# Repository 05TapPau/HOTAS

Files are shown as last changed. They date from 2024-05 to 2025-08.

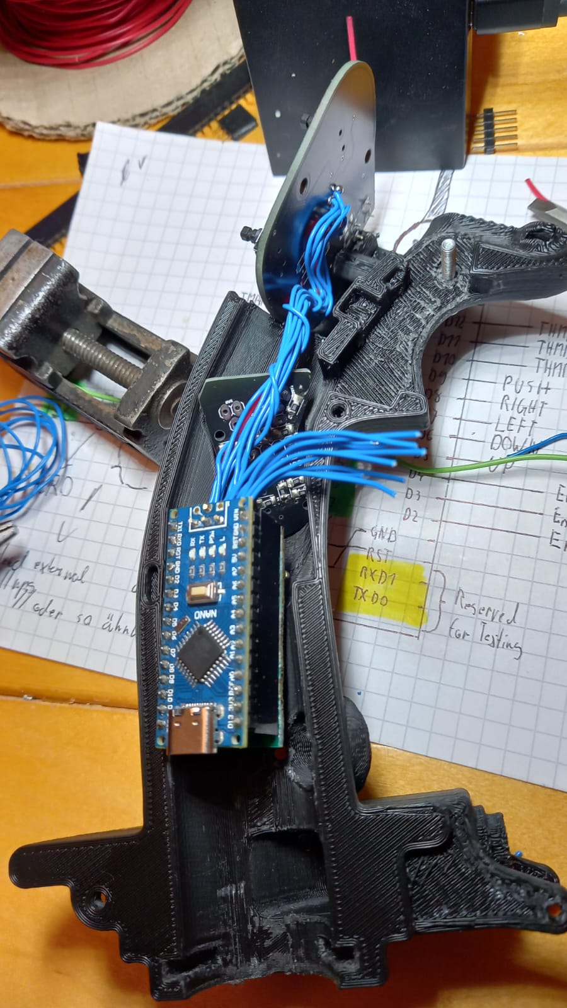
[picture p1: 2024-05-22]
Images/Assembly_03.jpg

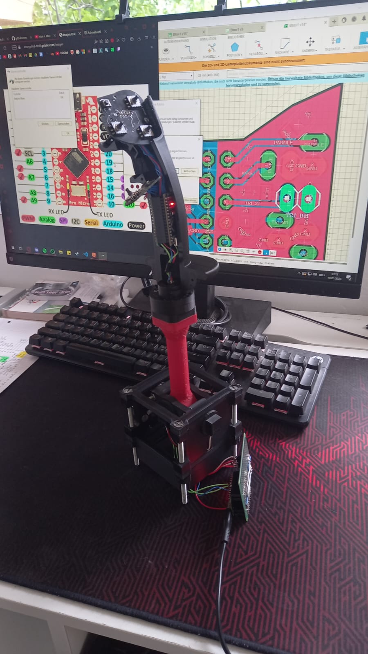
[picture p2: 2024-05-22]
Images/Testing_01.jpg

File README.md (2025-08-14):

Hi, im a student in a technological highschool and this is a project I did.
in this repo you should be able to find all things and sources to somewhat clone my project
well its not gonna be a copy and paste project for anyone trying cuz you have to figure our some stuff on your own or you ask me rreddit: https://www.reddit.com/user/gimme_da_meme/

maybe i will add some links in here sometime but right ow its 23:28 where im at and i wanna go to sleep so yeah sorry for that i guess

anyways have a great night/morning/day

Copyright (C) 2025 "Paul Tappeiner" aka "05TapPau"
These Sources are freely available: 
You may distribute and/or modify them under the terms of the GNU General Public License, either 
according to version 3 of the license or any later version, as published by the Free Software Foundation.
These Sources are distributed in the hope that they will be useful, but WITHOUT ANY WARRANTY; even without 
the implied warranty of MERCHANTABILITY or FITNESS FOR A PARTICULAR PURPOSE. 
For further details, see the GNU General Public License.

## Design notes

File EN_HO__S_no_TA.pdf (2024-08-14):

Name | | class school
5.10.2023 | - | 23.05.2024

Yearly project: HO(TA)S

Hands on (Throttle and) Stick

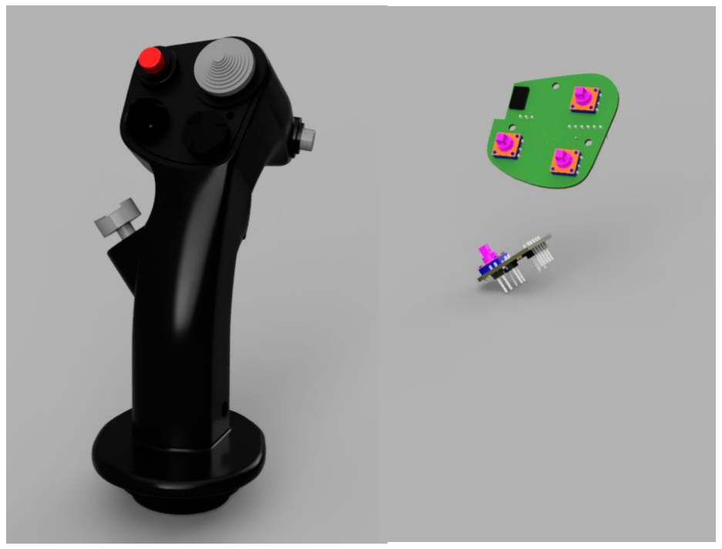
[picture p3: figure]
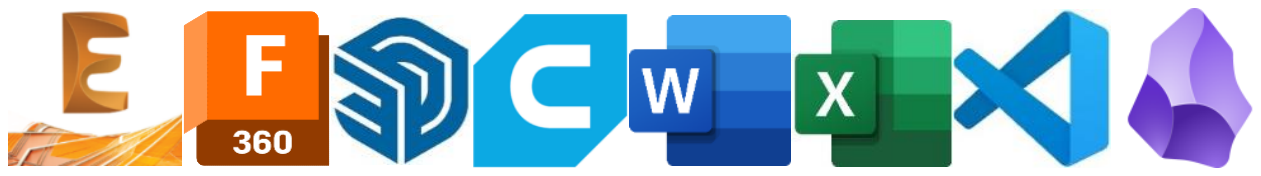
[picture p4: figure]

Contents

Projevtoverview

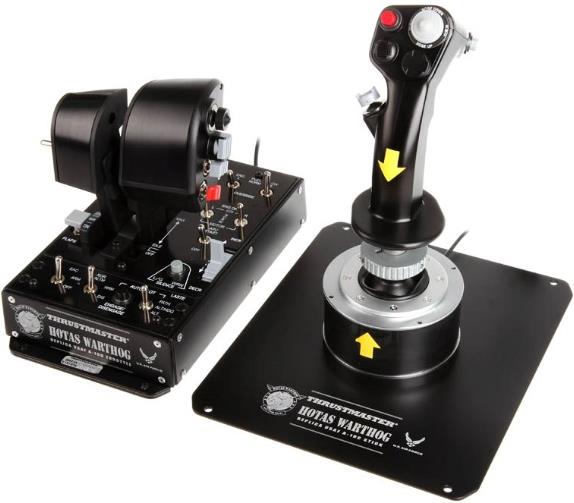
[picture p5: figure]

A Hands On Throttle And Stick (Image to the right) is a computer input device that visually resembles the control surfaces that can be found in an airplane/helicopter. It is mainly used to learn and train the flying of real aircraft in simulators, and for some years now they have also been used in the entertainment sector to control flying objects (airplanes, helicopters, spaceships, etc.) in computer games and simulations such as DCS, WarThunder, etc. The main module of the HOTAS, the flightstick or joystick, performs the main functions of “roll” and “pitch” (illustration on the right). The fact that these axes are corrected analogously in a HOTAS means that much greater precision can be achieved than would ever be possible with a keyboard. There are also buttons on the stick for entering other commands.

Main Goal

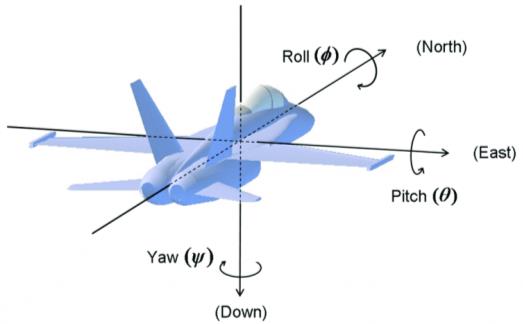
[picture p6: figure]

The aim of the project was to work on and complete a project that was started outside of school. It should consist of two Arduinos, one of which is in the base and another in the joystick. These two µCs are to exchange the required data via I2C and pass it on to the PC via the USB interface. In addition to the obvious advantages of having more pins available, the choice of two Arduinos also offers the advantage of being able to add further modules via the I2C bus using the Arduino in the base, with just a few lines of code.

Optional Goals

Optional 1

For the time being, the addition of a further module was planned as an optional target. This module would be the throttle. It is usually located to the left of the pilot in real aircraft and allows stepless control of the thrust in airplanes or the pitch of the rotors in helicopters as well as control over the speed of the turbine.

Optional 2

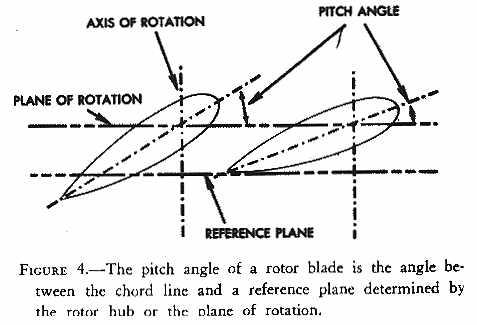
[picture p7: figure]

Another option was the output of data, which could be retrieved from the simulation via third-party software, on digital or analog displays mounted near the joystick. However, this goal was only a rough idea from the beginning and was never really started. However, it would be a good placeholder if there was still a lot of time left at the end of the year. However, this was not the case and so this optional goal was already discarded at the end of January.

Implementation

Project planning

Research 3D model

The project was started with research on different joystick models to get a feeling for what is needed on a joystick. After some first own
drawing attempts (pictures on the right), it was
decided to use an open source 3D model of a F-16 /
A10 joystick. As it turned out that it would take a lot of time to draw it completely by oneself. It was decided to use the 3D model from JFlyer81, as it is based on a 3D scan of a real joystick.

However, since the final joystick consists not only of
a joystick, but also a part for mounting the joystick,
the so-called gimbal. The basic idea here was a

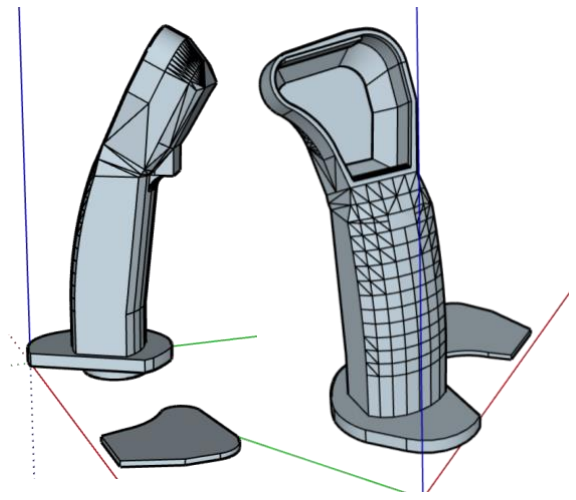
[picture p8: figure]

construct that could rotate around two axes. During the first attempts to design our own gimbal, we quickly realized that it was very difficult to draw a concept that would keep the force that counteracts the movement of the joystick linear and prevent it from noticeably “snapping” in the middle position, which would be optimal for a joystick. After lengthy research, a design for a gimbal that roughly met the requirements was found (olukelo >> Thingiverse). This gimbal was then used as the basis and further modified.

3D drawing/adjustment

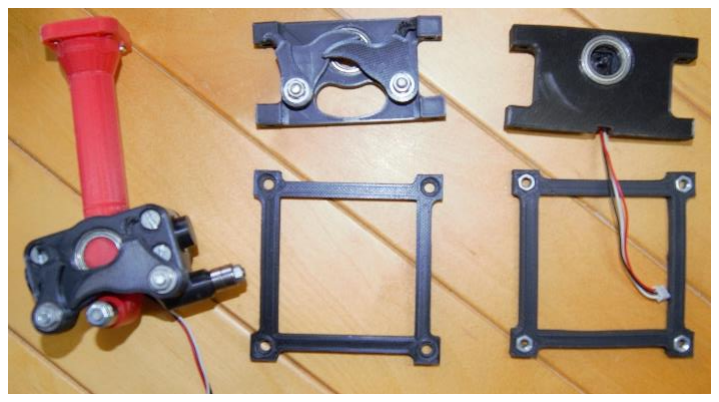
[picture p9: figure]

These modifications were mainly related to the adjustment of the exploitation method from Hall sensors to poorer/less precise potentiometers and various smaller adjustments concerning ball bearings, cable ducts and mounting points for nuts etc.. The next big and important adjustment was the modification of the joystick shaft which firmly connects the gimbal and joystick.
The original connection was a pure
plug-in connection which relied purely
on the friction of the materials. There was also a connection option based on two M5 screws, but I also found this unsuitable as I wanted the joystick to be able to be replaced quickly if necessary.

As a result, I redesigned the connection
mechanism into a variant that locks. The joystick is pressed onto the connector with a 45° turn to the base and turned back to a 0° position, whereby the joystick locks with the shaft and is firmly connected to it. After an unsuccessful attempt with a makeshift circuit board, the electronic connection is provided by a push-in connector, which is normally used for audio systems in the avionics sector (see picture on the left). After the basic model of the complete joystick assembly was ready, the planning of the electrical components was started.

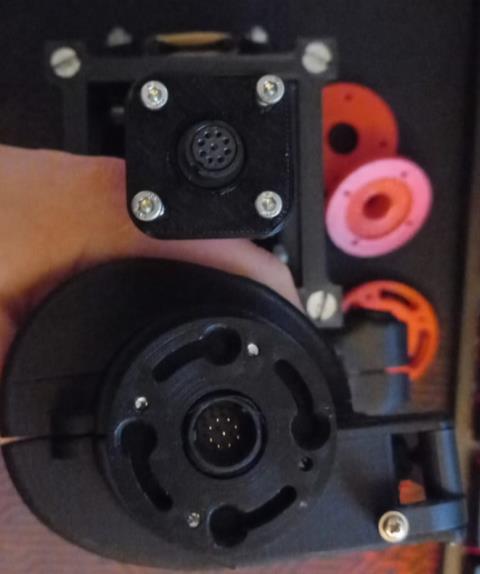
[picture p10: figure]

2 “Twist on quickconect”, gimbal top, joystick bottom

1 Individual components of the gimbal are recognizable ball bearings and potentiometers

Electronic components

The basic idea here was to have an independent Arduino in the joystick which takes care of reading out the various buttons and sending them to another Arduino which then takes care of sending this data to the PC. Reading the 26 buttons in the joystick should still prove to be a hurdle, but more on that later. In the base of the joystick is an Arduino Micro, which has the properties to appear as a keyboard/mouse/controller under Windows. This reads the data sent from the Arduino Nano and passes it on, and also passes on the values of the potentiometers.

The potentiometers used here were potentiometers which had a rotation range of approx. 90°, instead of the classic 300°-320°, which corresponded almost exactly to the possible rotation angle of the gimbal.

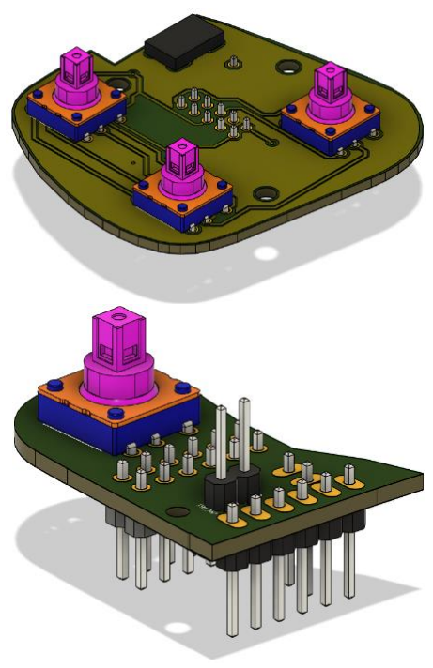
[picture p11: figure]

In the first prototype, the buttons were small holders for
five 5*5*3 mm buttons attached to the housing with screws. However, this structure was very complex, unreliable and prone to errors. It was therefore decided to replace these brackets with an integrated 5-way button, which, however, requires a circuit board. The next step was therefore to design one or two circuit boards that corresponded to the joystick housing, a cut was made in the housing so that the circuit boards could be firmly installed in the housing. This process was repeated for the side circuit board and continued accordingly. As there is a front board and a thumb board, which are in different positions (on the left where the thumb is and on top of the front panel).

Electronic implementation

As the Arduino Nano only has 14 digital and 8 analog pins, two of which are lost for the communication between the two Arduinos via I2C, only 20 pins remain. As already mentioned, there are 26 buttons in the joystick. However, since the 5 way buttons have a common supply pin, they can be switched on and off sequentially and the 5 different lines of the respective pins can be combined with the corresponding ones. This means that the 15 pins that would have to be used for this can be reduced to 5 pins for reading out the statuses and 3 pins for switching the button units on and off. For the other

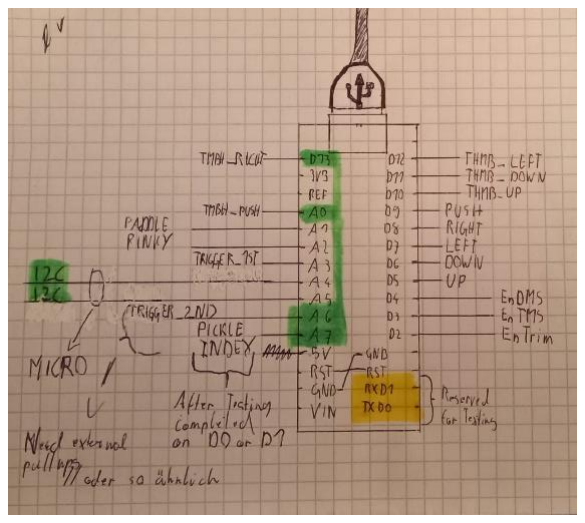
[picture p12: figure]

3 Pinout/use of pins => Nano mounted in the stick itself buttons, these were not solved using the same system, but were pulled individually onto the µC, as there were now enough pins available and the wiring would not have been much easier.

Schematic front PCB:

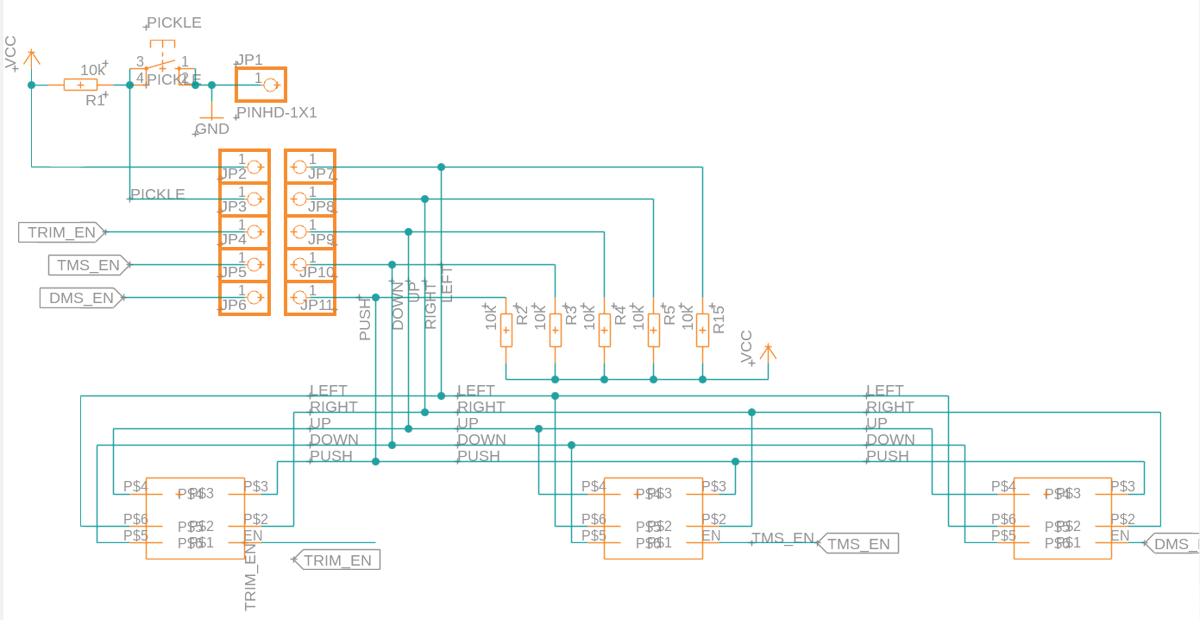
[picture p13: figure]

4 Schematic front PCB

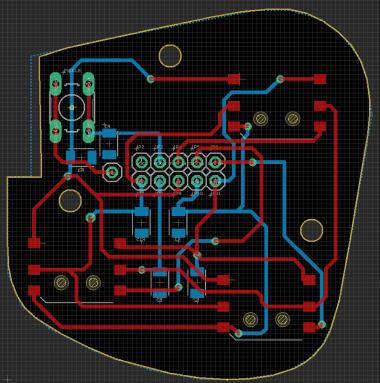
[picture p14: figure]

Here you can clearly see how the outputs of the various button units all go to the same five conductors. It should be noted that since the pins are all configured to pull-ups, only the unit that is currently switched to GND by the µC can control the outputs. It should also be mentioned here that the names TRIM, TMS, DMS refer to control characteristics of the
airplane, I refer to the
illustration on the right,
and these have only been adopted for orientation purposes.

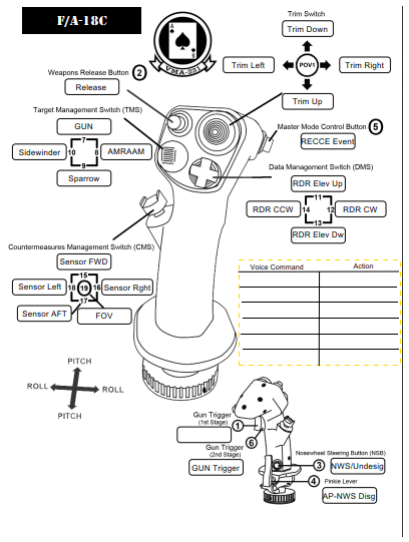
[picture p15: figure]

5 Related PCB

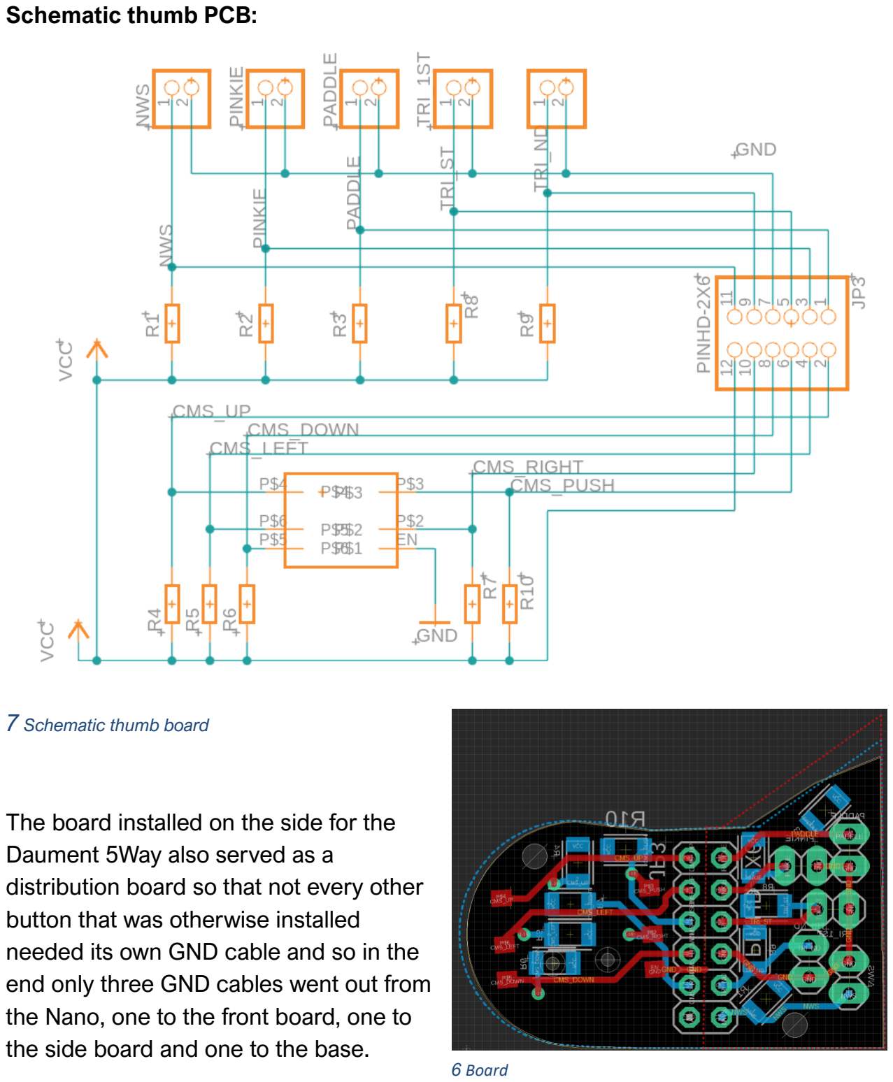
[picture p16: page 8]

Schematic thumb PCB:

7 Schematic thumb board

The board installed on the side for the Daument 5Way also served as a distribution board so that not every other button that was otherwise installed needed its own GND cable and so in the end only three GND cables went out from the Nano, one to the front board, one to the side board and one to the base.
6 Board

Wiring

In practice, the cabling no longer looked so neat and tidy, as everything had to fit into a very limited space. On the right you can see that, despite the reduction to 10 cables, it became a little confusing.

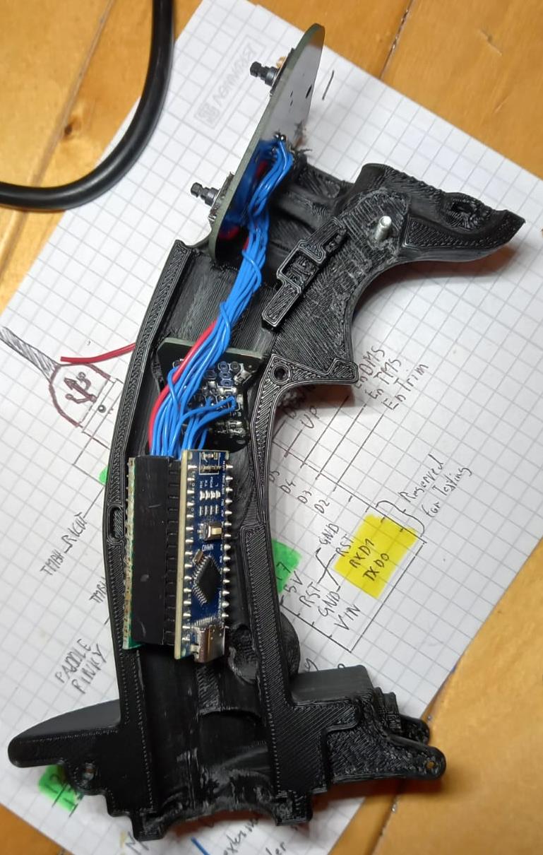
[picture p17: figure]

Software

The software running on the Arduinos was developed at the same time as the setup was being planned. If you start at the base, there is a library on the Arduino Micro which ensures that the Micro appears as an HID. This is then extended with the necessary joystick code so that the Micro can work or be recognized as a joystick.

The Micro writes the data read out via the potentiometers to the respective X/Y axes and accepts the incoming data from the buttons via I2C and passes it on to the PC.

The nano in the joystick assumes the underlying role here and sends the states of the buttons via I2C on request from the micro. This communication takes place via the Arduino's own I2C library.

8 Joystick during soldering

9 Joystick during soldering

Finalization and testing phase

The actual test phase of this project was always continuous alongside the development, as a first prototype already existed. This provided a great starting point, as you could switch from the digital to the physical while planning something and get a good idea of what still needed to be changed and adapted. During the finalization phase, something unfortunately went wrong with the delivery of the circuit boards via DHL, which meant that the boards only arrived a week late, which limited the schedule somewhat but was not worth mentioning until the end. Once all the parts were on site, the assembly could begin and after about two to three afternoons the final assembly was completed. The code that had already been written in March was then adapted a little and loaded onto the controllers. After a few
small adjustments (filing, soldering), the final
prototype was ready and the protocol was also

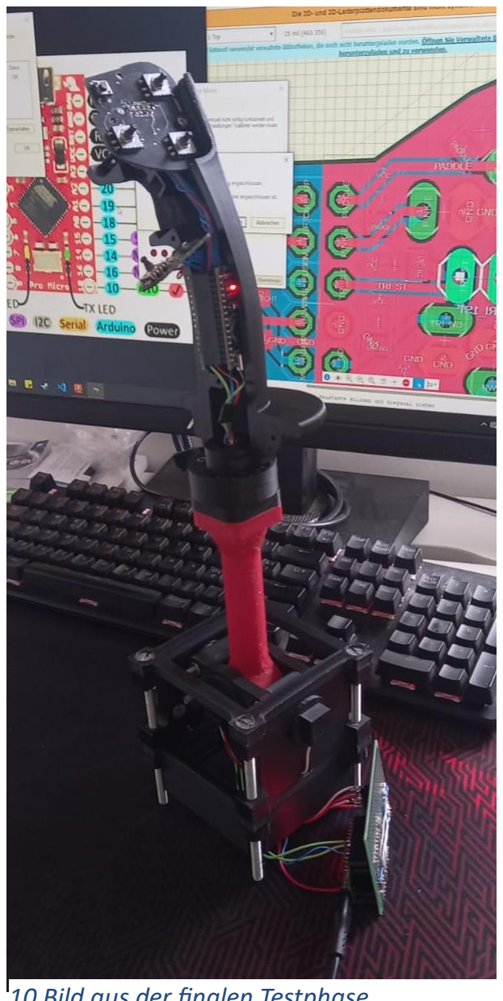
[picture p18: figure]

finalized. | 10 Bild aus der finalen Testphase

Sources:

OpenSource Code

used Joystick-Lib (https://github.com/MHeironimus/ArduinoJoystickLibrary)

GitHub for this project (https://github.com/05TapPau/HOTAS_Base_module)

3D-Models

Stick Base unedited (https://www.thingiverse.com/thing:4544115)

Gimbal unedited (https://www.thingiverse.com/thing:2496028)

GitHub edited stl s (https://github.com/05TapPau/HOTAS)

Images reference etc

https://shop.thrustmaster.com/it_it/hotas-warthog.htmlhttps://www.researchgate.net/figure/An-illustration-of-the-three-angles-yaw-pitch-and-roll-returned-by-the-Hype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 (https://www.researchgate.net/figure/An-illustration-of-the-three-angles-yaw-pitch-and-roll-returned-by-the-Hyper-IMU_fig1_329603549)

https://www.digitalcombatsimulator.com/upload/iblock/49a/HOTAS.png

- You should also be able to find images on the GitHub.

Legal or smth I aint no lawyer

If you own the intellectual right to any of the above mentioned things and im not allowed to use them please let me know I am pretty sure that this should al be okay but anyways im just human and probably also make mistakes.

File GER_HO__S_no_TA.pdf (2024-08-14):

Name | | class school
5.10.2023 | - | 23.05.2024
| FÜLA

Projekt: HO(TA)S

Hands on (Throttle and) Stick

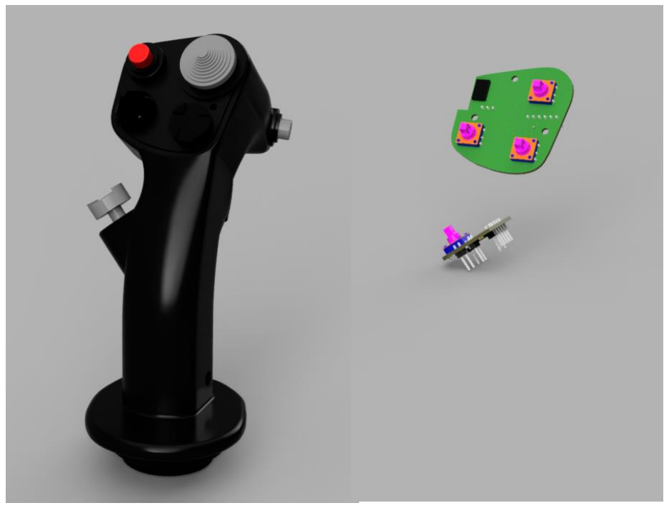
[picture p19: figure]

Inhalt

Projektübersicht


Ein Hands On Throttle And Stick (Abbildung rechts) ist ein Computereingabegerät welches optisch an die Kontrollflächen, welche in einem Flugzeug/Helikopter gefunden werden können, erinnert. Es wird hauptsächlich verwendet, um in Simulatoren das Fliegen von echten Fluggeräten zu Lernen und zu trainieren, seit einigen Jahren werden sie auch im Unterhaltungssektor zum Lenken von Flugobjekten (Flugzeuge, Hubschrauber, Raumschiffe etc.) in Computerspielen und Simulationen wie DCS, WarThunder etc. Das Hauptmodul des HOTAS, der Flightstick oder Joystick, übernimmt die Hauptsächlichen Funktionen von „Roll“ und „Pitch“ (Abbildung rechts). Dadurch dass diese Achsen in einem
HOTAS analog korrigiert werden, erreicht man
eine viel höhere Präzision als man mit einet


Tastatur Jeh erreichen würde. Desweitern finden sich auf dem Stick noch Knöpfe zur Eingabe von weiteren Befehlen.

Hauptziel

Das Ziel des Projektes war es ein außerhalb der Schulzeit angefangenes Projekt auszuarbeiten und fertigzustellen. Es soll aus zwei Arduinos bestehen, wovon einer sich in der Basis befindet und ein weitere im Joystick. Diese zwei µC sollen über I2C die benötigten Daten austauschen und über die USB-Schnittstelle an den PC weitergeben. Die Wahl für zwei Arduinos bietet neben den offensichtlichen Vorteilen wie, dass nun mehr Pins zur Verfügung stehen, auch den Vorteil, dass man über den Arduino in der Basis noch weiter Module über den I2C Bus, mit Wenigen Zeilen Code, hinzufügen kann.

Optionale Ziele

Optional 1


Als optionale Ziele wurden vorerst noch die Addition eines weiteren Modules vorgesehen. Dieses Modul wäre damit der Throttle oder zu Deutsch der Schubregler. Er befindet sich in echten Fluggeräten meist zur Linken des Piloten und erlaubt eine Stufenlose Kontrolle des Schubes in Flugzeugen oder Pitch der Rotoren in Hubschraubern sowohl als Kontrolle über Drehzahl der Turbine.

Optional 2

Ein weiteres Optional war die Ausgabe von Daten, welche über Dritt Software aus der Simulation geholt werden können, an Digitalen oder Analogen Anzeigen, welche in der Nähe des Joysticks montiert, werden könnten. Dieses Ziel war jedoch von Anfang an nur eine grobe Idee und wurde nie wirklich angefangen. Es wäre jedoch ein guter Platzhalter, wenn am Ende des Jahres noch viel Zeit übrig wäre. Dies war jedoch nicht der Fall und so wurde dieses optionale Ziel schon Ende Januar verworfen.

Umsetzung

Projekt-Planung

Recherche 3D Model

Gestartet wurde das Projekt mit Recherchen nach verschiedenen Joystickmodellen, um ein Gefühl dafür zu bekommen was alles nötig ist
auf einem Joystick zu haben. Nach einigen ersten
eigenen Zeichenversuchen (Bilder rechts), wurde
sich jedoch entschieden ein open source 3D-Modellen von einem F-16 / A10 Joystick zu verwenden. Da sich herausstellte, diesen komplett selbst zu zeichnen Unmengen An Zeit aufbrauchen würde. Es wurde sich für das 3D Modell von JFlyer81 (https://www.thingiverse.com/JFlyer81) entschieden, da diese auf einem 3D-Scan
eines echten Joysticks basiert.

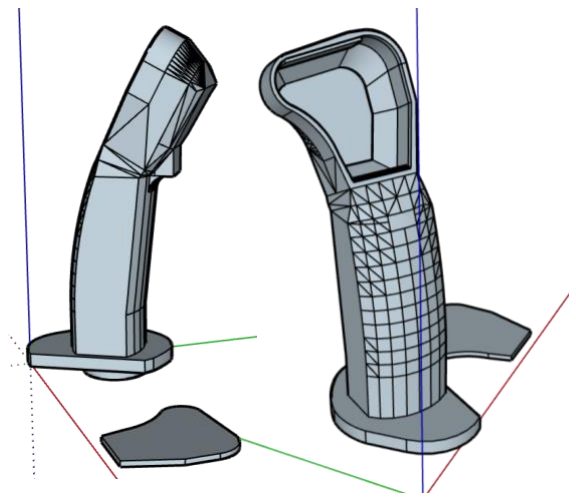
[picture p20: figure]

Da der schlussendliche Joystick jedoch nicht nur aus einem Joystick besteht, sondern auch einem Teil zur Montage des Joysticks, dem sogenannten Gimbal. Die Grundidee hier war ein Konstrukt, welches sich um zwei Achsen drehen kann. Bei den ersten Versuchen ein eigenes Gimbal zu designen wurde schnell festgestellt, dass es hier sehr schwer ist ein Konzept zu zeichnen welches die Kraft, welche der Bewegung des Joysticks entgegenwirkt, linear zu halten und ein spürbares „Einrasten“ in der Mittelposition zu verhindern, was optimal wäre für einen Joystick.

Nach längerer Recherche und Austausch mit einem Designer (olukelo (https://www.thingiverse.com/olukelo) >> Thingiverse) welcher schon ein Gimbal designt hat, welches ca. den Ansprüchen entsprach. Dieses Gimbal wurde dann als Basis verwendet und weiter modifiziert.

3D Zeichnung/Anpassung


Diese Modifikationen bezogen sich hauptsächlich auf die Anpassung der Ausbeutungsmethode von Hall Sensoren zu schlechteren/Unpräziseren Potentiometern und unterschiedlichen kleineren Anpassungen was Kugellager, Kabelschächte und befestigungspunkte für Muttern etc. angingen. Die nächste große und wichtige Anpassung war die Änderung vom Joystick-Schaft welcher
Gimbal und Joystick fest verbindet. Die
originale Verbindung war eine reine
Steckverbindung welche sich reine auf Reibung der Materialien verlies, des Weiteren gab es noch eine Verbindungsoption, welche auf zwei M5 Schrauben basiert, jedoch fand ich auch diese unpassend da der Joystick in meiner Vorstellung die Möglichkeit bietet, bei Bedarf, schnell ausgetauscht zu werden.

Aufgrund dessen wurde der
Verbindungsmechanismus von mir in eine Variante umgezeichnet, welche verriegelt. Der Joystick wird mit einer 45° Drehung zur Basis au den Verbinder gedrückt und zurück in eine 0° Position gedreht, dabei verriegelt der Joystick sich mit dem Schaft und ist fest damit verbunden. Die elektronische Verbindung übernimmt hierbei nach einem weder gescheiterten noch geglückten Versuch mit einer Provisorischen Platine, ein Druck-Stecker, welcher normalerweise für Audiosysteme im Avionik Bereich verwendet wird (Siehe Bild links). Nachdem das Grundmodell des kompletten Joystick-Zusammenbaus stand, wurde mit der der Planung der elektrischen Komponenten gestartet.


2 Twiston Quickconect, Gimbal oben, Joystick unten

1 Einzelnen Komponenten des Gimbals erkennbar sind Kugellager sowie Potentiometer

Elektronischen Komponenten

Die Grundidee war hier, einen eigenständigen Arduino im Joystick zu haben welcher sich darum kümmert die verschiedenen Knöpfe auszulesen und an einen anderen Arduino zu schicken welcher sich darum kümmert, dass diese daten dann am PC ankommen. Das Auslesen der 26 Knöpfe im Joystick sollte sich noch als eine Hürde erweisen jedoch dazu später mehr. In der Basis des Joysticks befindet sich ein Arduino Micro, welcher über die Eigenschaften verfügt als eine Tastatur/Maus/Controller unter Windows zu erscheinen. Dieser liest die gesendeten Daten vom Arduino Nano aus und übergibt diese, des Weiteren gibt er noch die Werte der Potentiometer weiter.

Die verwendeten Potentiometer waren hier Potentiometer welche über eine Drehbereich von ca. 90°, anstelle von den klassischen 300°-320°, hatten, was fast genau dem möglichen Drehwinkel vom Gimbal entsprach.

Die Knöpfe waren im ersten Prototyp kleine per
Schrauben im Gehäuse angebrachte Halterungen für fünf 5*5*3 mm Knöpfe. Diese Gebilde war jedoch sehr komplex, unzuverlässig und Fehleranfällig. Deshalb wurde sich entschieden diese Halterungen durch einen integrierten 5-Wege Knopf zu ersetzen, welcher jedoch eine Platine benötigt. Nächster Schritt war also eine beziehungsweise Zwei Platinen zu designen welche dem Joystickgehäuse entsprach, im Gehäuse wurde ein Einschnitt gemacht, damit die Platinen fest im Gehäuse verbaut werden können. Dieser Vorgang wurde für die seitliche Platine wiederholt und dementsprechend
fortgeführt. Da es eine Front-Platine gibt und eine
Thumb-Platine, welche sich an den unterschiedlichen

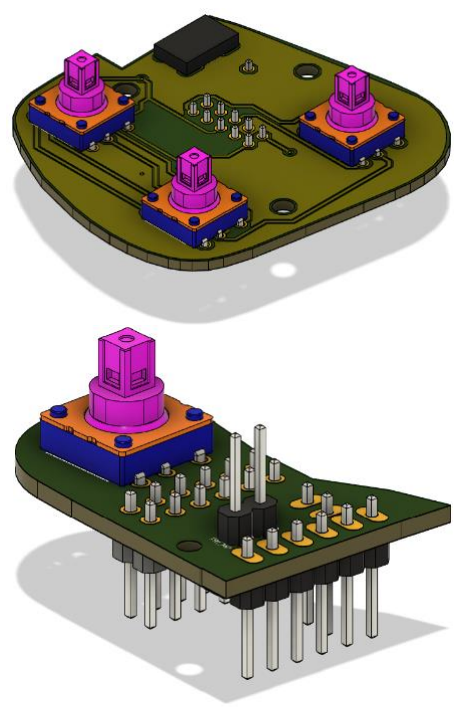
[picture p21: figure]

Positionen befinden (link wo der Daumen ist und oben auf der Frontplatte).

Elektronischen Umsetzung

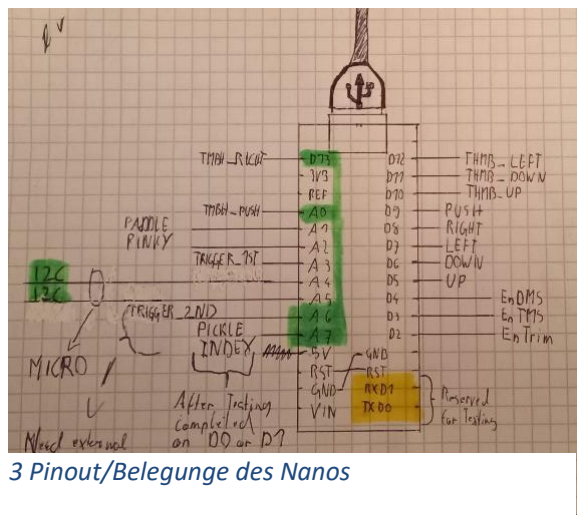
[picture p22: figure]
3 Pinout/Belegunge des Nanos

Da der Arduino Nano nur über 14 digitale und 8 Analoge Pins verfügt, davon jedoch schon zwei für die Kommunikation der zwei Arduinos über I2C verloren gehen, bleiben nur 20 pins übrig. Wie vorher schon erwähnt, befinden sich jedoch 26 Knöpfe im Joystick. Da die 5 Wegknöpfe jedoch über einen gemeinsamen Versorgungspin verfügen, können sie sequenziell ein und ausgeschaltet werden und die 5 verschiedenen Leitungen der jeweiligen

Pins können mit den dementsprechenden zusammengelegt werden. Dadurch können die 15 Pins, die dafür verwendet werden müssten auf 5 Pins zum Auslesen der Zustände und 3 Pins um Ein und Ausschalten der Knopfeinheiten reduziert werden. Bei den anderen Knöpfen wurden diese nicht über dasselbe System gelöst, sondern einzeln auf den µC gezogen, da nun genügend Pins zur Verfügung standen und die Verkabelung nicht viel einfacher geworden wäre.

Schematic der Frontplatine:


4 Schematic der Frontal verbauten Platine


Hier läst sich nochmal gut erkennen wie die gleichen die Ausgänge der verschiedenen Knopfeinheiten alle auf die selben fünf Leiter gehen. Dabei ist zu beachten, da die Pins alle auf Pullups konfiguriert sind, dass eben immer nur diese Einheit die Ausgänge kontrollieren kann, welche gerade vom µC auf
GND geschalten wird.
Weiters ist hier noch
zu erwähnen dass, die
Namen TRIM, TMS, DMS sich auf Kontrolleigenschaften des Flugzeuges bezieh, dabei beziehe ich mich auf die Abbildung rechts, und diese nur Orientierungshalber übernommen wurden.

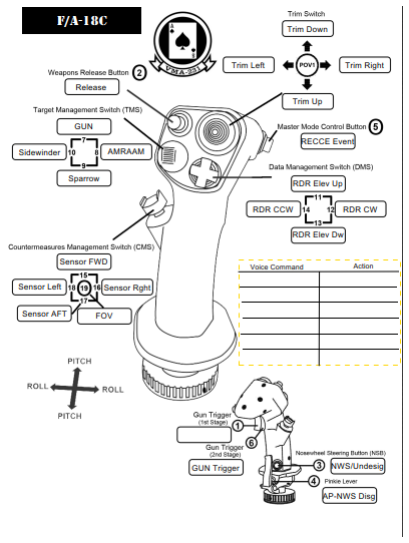
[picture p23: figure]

5 Dazugehöriges Board

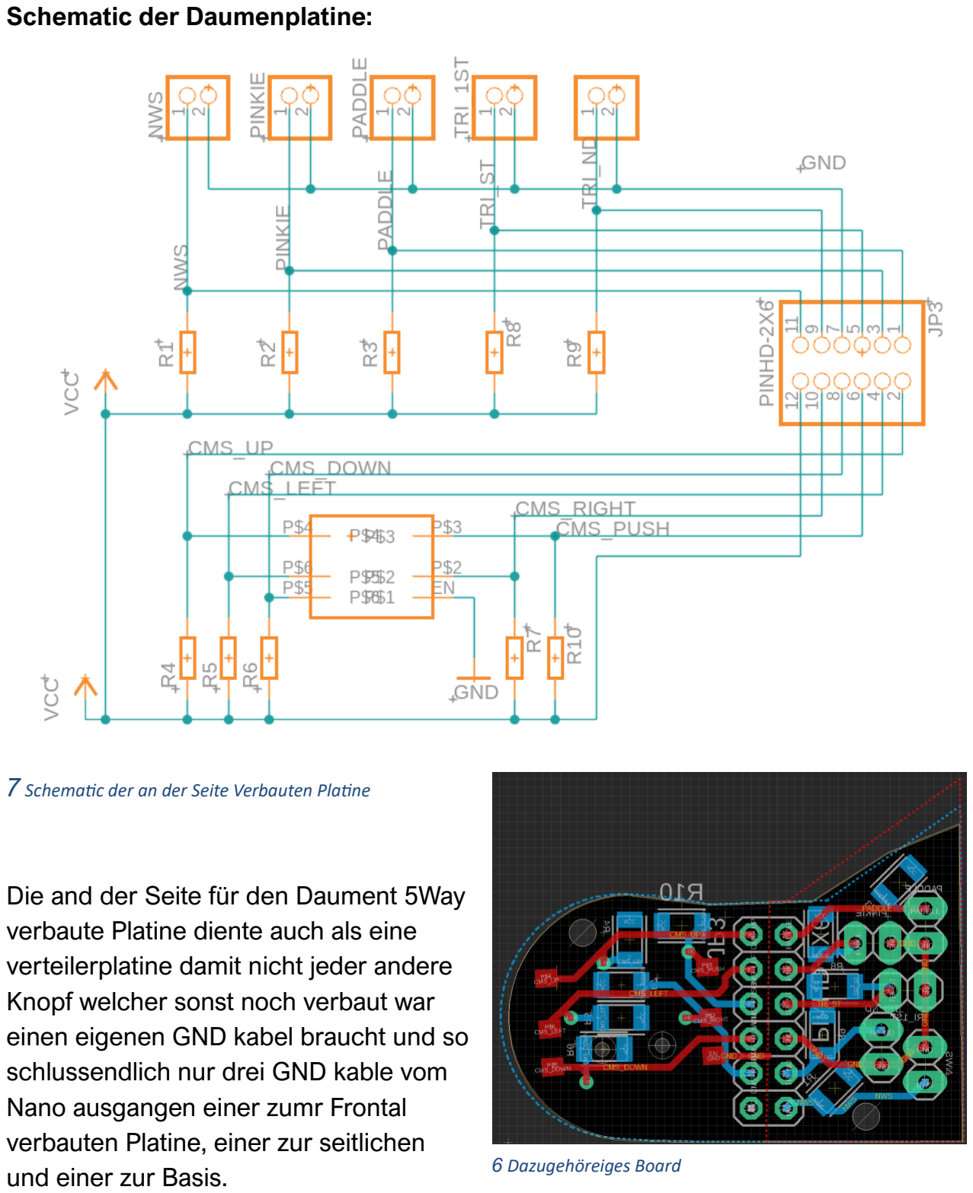
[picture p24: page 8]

Schematic der Daumenplatine:

7 Schematic der an der Seite Verbauten Platine

Die and der Seite für den Daument 5Way verbaute Platine diente auch als eine verteilerplatine damit nicht jeder andere Knopf welcher sonst noch verbaut war einen eigenen GND kabel braucht und so schlussendlich nur drei GND kable vom
Nano ausgangen einer zumr Frontal
verbauten Platine, einer zur seitlichen
und einer zur Basis. | 6 Dazugehöreiges Board


Praktische Verkabelung

In der Praxis sah die Verkabelung nicht mehr so sauber und ordentlich aus, da alles in einem sehr beschränkten raum Platz finden musste. Rechts ist zu erkennen, dass auch trotz der Reduzierung auf 10 Kabel es doch ein wenig unübersichtlich wurde.

Software
Zeitgleich zur Planung des Aufbaus wurde auch schon die auf den Arduinos laufende Software entwickelt. Wenn man bei der Basis anfängt, befindet sich auf dem Arduino Micro einerseits eine Bibliothek, welche sich darum kümmert, dass der Micro als HID aufscheint. Diese wird noch mit dem nötigen Joystick code erweitert, damit der Micro als Joystick arbeiten kann bzw. erkannt wird.

Der Micro schreibt die über die Potentiometer ausgelesenen Daten in die jeweiligen Achsen X/Y und übernimmt die über I2C eingehenden Daten der Knöpfe und gibt diese an den PC weiter.

Der Nano im Joystick übernimmt hierbei die unterliegende Rolle und schick auf Anfrage des Micros die Zustände der Knöpfe über I2C. Diese Kommunikation findet über die Arduino eigene I2C Bibliothek statt.

8 Joystick wärend des Lötens

Finalisierung und Testphase

Die eigentliche Testphase dieses Projekts war immer kontinuierlich neben der Entwicklung, da eben schon ein erster Prototyp existierte. Dieser bot eine super Ausgangsbasis, da man während man etwas plante auch vom Digitalen auf das Physische übergehen konnte und sich ein gutes Bild erzeugen konnte was noch geändert und angepasst werden muss. In der Phase der Finalisierung ging leider bei der Lieferung der Platinen über DHL etwas schief wodurch die Platinen erst eine Woche verspätet ankamen, was den Zeitplan etwas einschränkte aber bis zum Schluss nicht weiters erwähnenswert. Nachdem alle Teile vor Ort waren konnte mit dem Zusammenbau begonnen werden und nach ca. zwei bis drei Nachmittagen war der finale Aufbau fertig. Danach wurde der schon im März fertiggeschriebene Code ein wenig angepasst und auf die Controller geladen. Nach einigen kleinen Anpassungen (Feilen, Löten) war der Finale Prototyp fertig und das Protokoll wurde auch finalisiert.

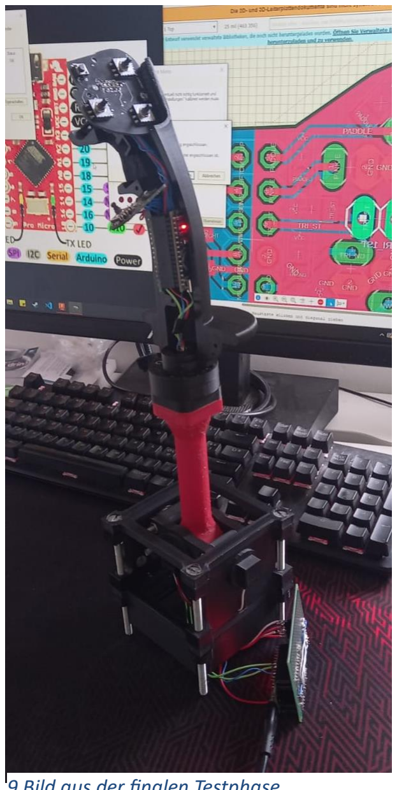
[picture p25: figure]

9 Bild aus der finalen Testphase

Quellen:

Programme

verwendete Joystick-Library (https://github.com/MHeironimus/ArduinoJoystickLibrary)

GitHub mit dem Code zu diesem Projekt (https://github.com/05TapPau/HOTAS_Base_module)

3D-Modelle

Stick Basis unbearbeitet (https://www.thingiverse.com/thing:4544115)

Gimbal unbearbeitet (https://www.thingiverse.com/thing:2496028)

GitHub zu den eigenen 3D Modellen (https://github.com/05TapPau/HOTAS)

Bilder

https://shop.thrustmaster.com/it_it/hotas-warthog.htmlhttps://www.researchgate.net/figure/An-illustration-of-the-three-angles-yaw-pitch-and-roll-returned-by-the-Hype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 (https://www.researchgate.net/figure/An-illustration-of-the-three-angles-yaw-pitch-and-roll-returned-by-the-Hyper-IMU_fig1_329603549)

https://www.digitalcombatsimulator.com/upload/iblock/49a/HOTAS.png

- Eigene Bilder sollten auch im GitHub zu finden sein.

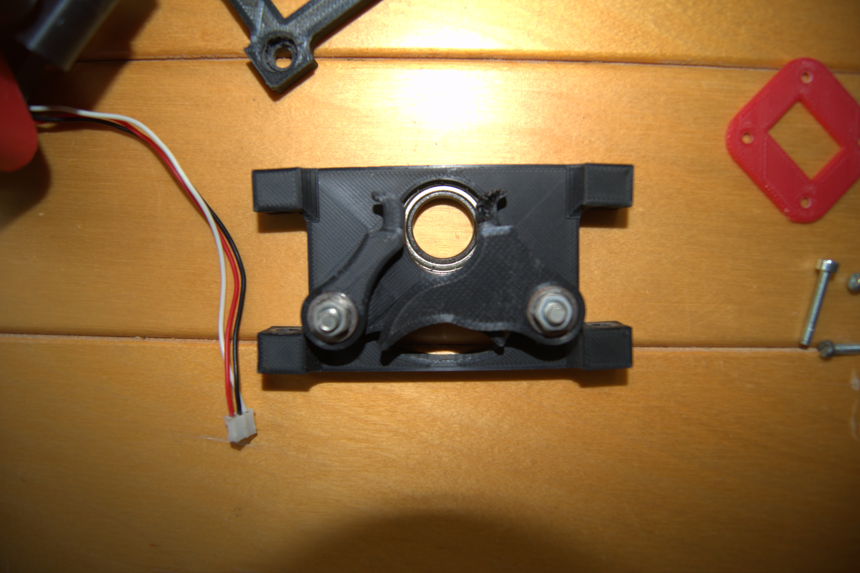
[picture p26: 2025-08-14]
Images/Shell_cams.jpg

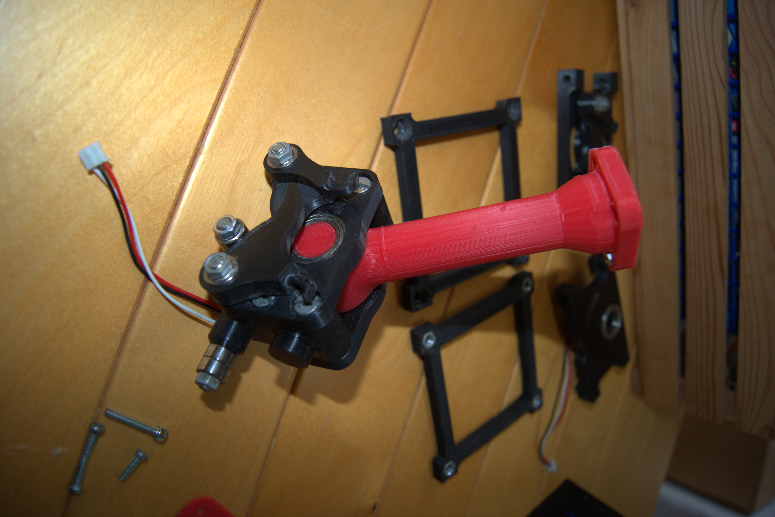
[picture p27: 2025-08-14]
Images/cam_and_hub_01.jpg

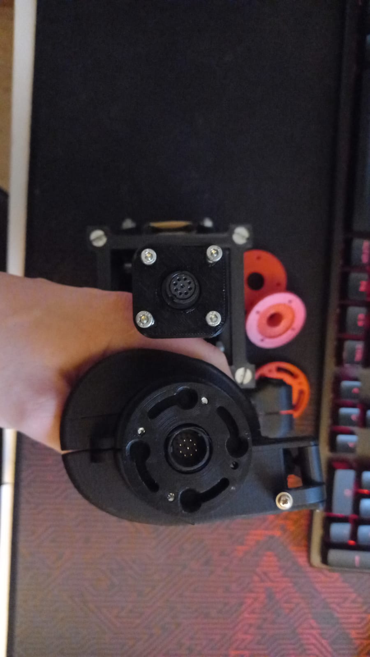
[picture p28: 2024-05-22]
Images/Twiston.jpg

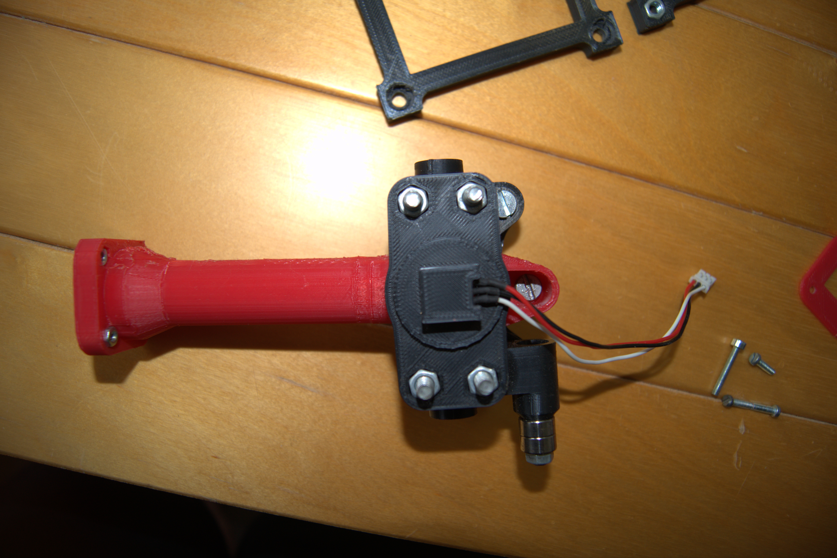
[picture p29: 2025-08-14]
Images/cam_and_hub_02.jpg

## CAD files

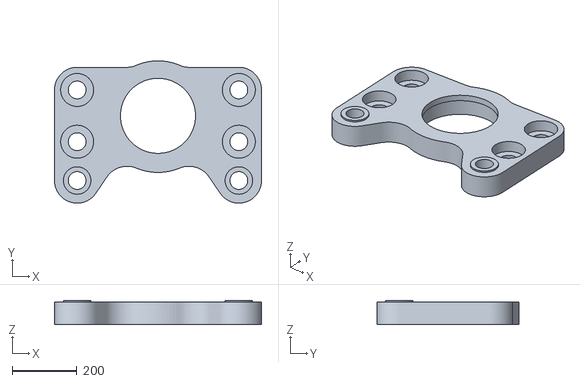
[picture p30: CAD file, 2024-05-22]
ReadyToPrint_Gimbal/gimbalcore_no_pot v3.stl
640.0 x 440.0 x 75.0

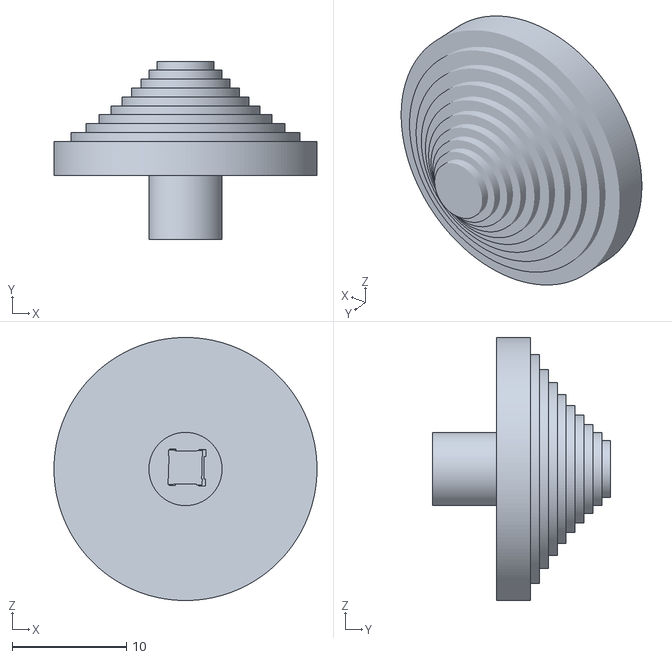
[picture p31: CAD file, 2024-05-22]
ReadyToPrint_Joystick/Trim_Hat.stl
23.0 x 15.6 x 23.0

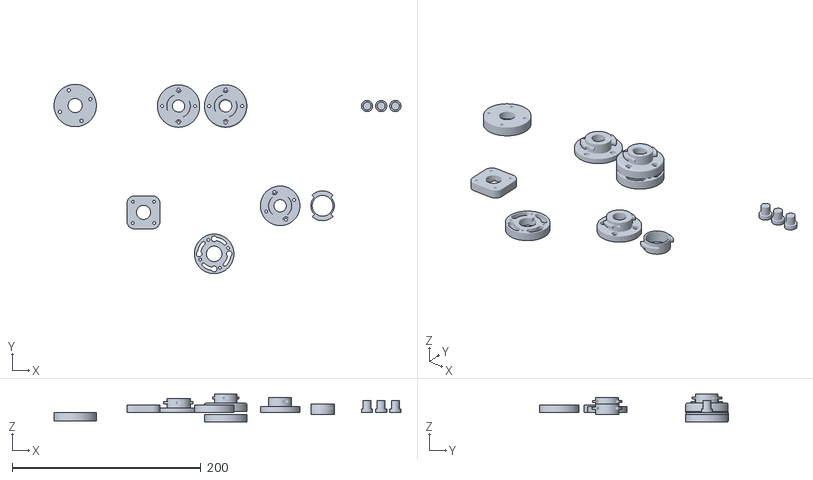
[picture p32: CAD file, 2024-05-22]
ReadyToPrint_Gimbal/Twiston_Adapter.stl
368.1 x 200.8 x 29.6

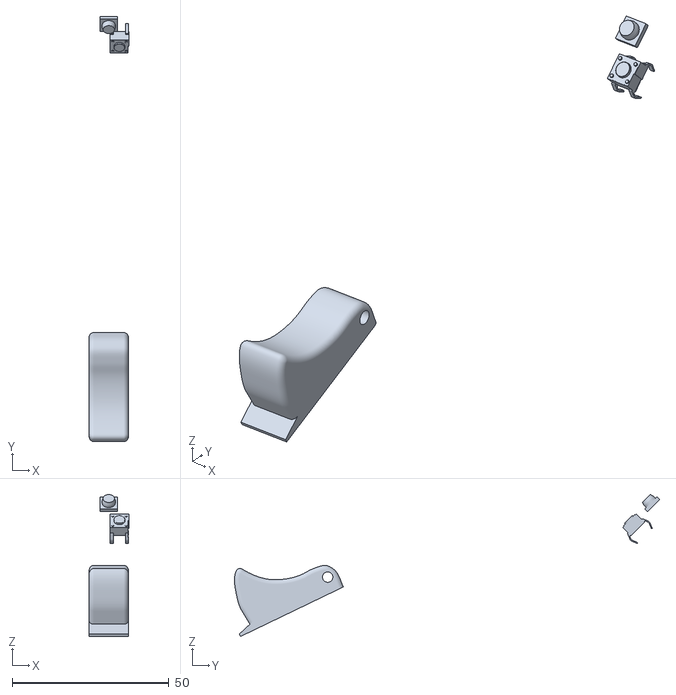
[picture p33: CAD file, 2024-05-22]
ReadyToPrint_Joystick/Trigger.stl
12.6 x 135.6 x 45.3

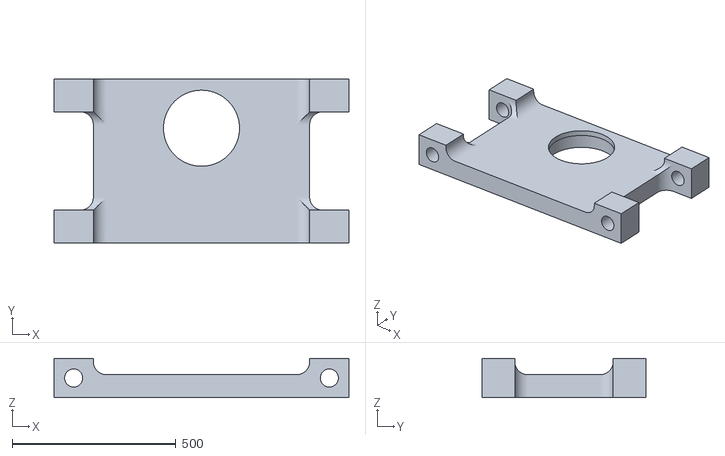
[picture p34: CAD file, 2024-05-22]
ReadyToPrint_Gimbal/gimbal_frame_pot_v1.stl
900.0 x 500.0 x 120.0

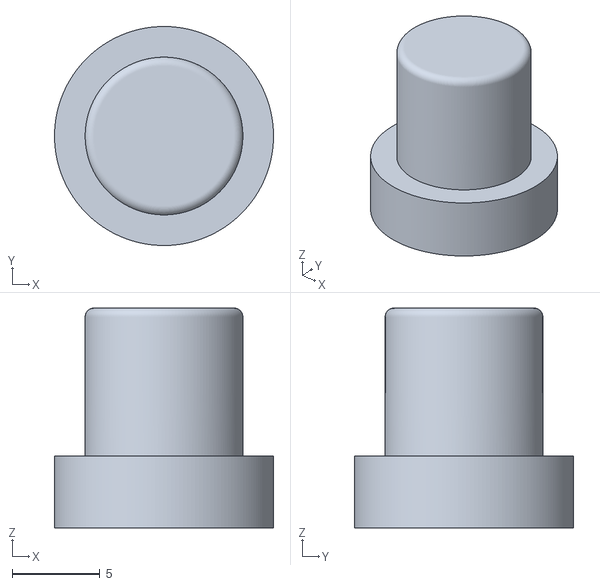
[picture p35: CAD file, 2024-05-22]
ReadyToPrint_Joystick/Pinkie.stl
12.5 x 12.5 x 12.6

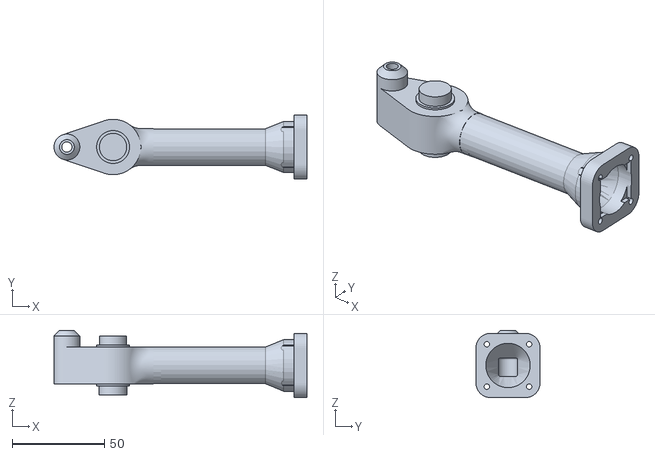
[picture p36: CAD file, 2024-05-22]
ReadyToPrint_Gimbal/Shaft_short_twiston_compatible.stl
137.0 x 34.8 x 36.4

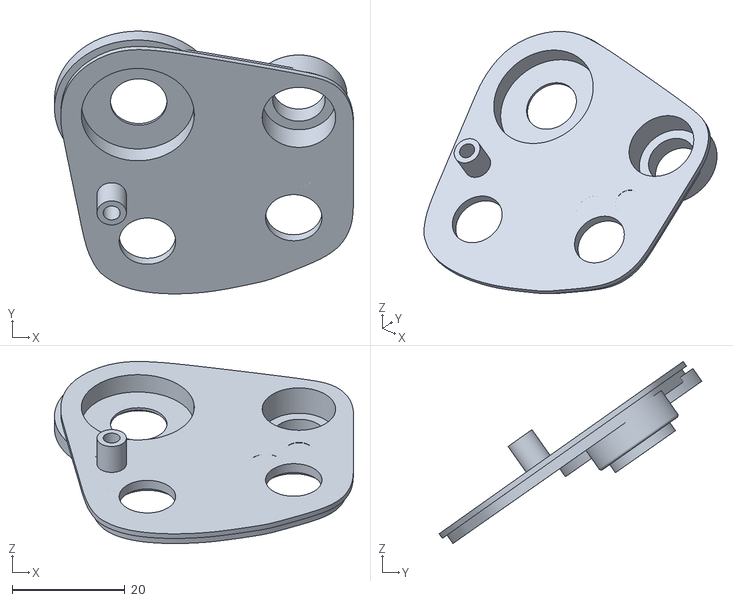
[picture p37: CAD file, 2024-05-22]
ReadyToPrint_Joystick/Front.stl
52.9 x 46.5 x 32.2

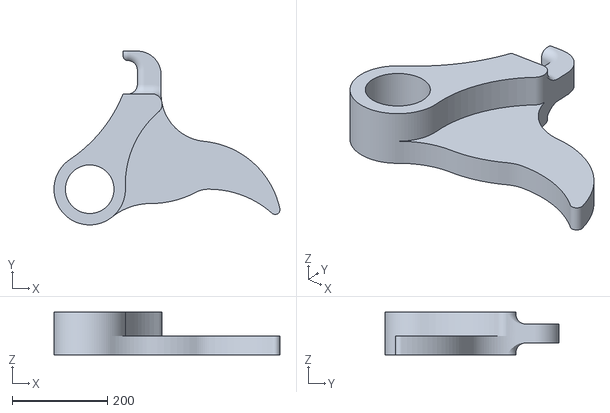
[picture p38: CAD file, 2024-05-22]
ReadyToPrint_Gimbal/gimbal_cam v4.stl
474.6 x 365.0 x 90.0

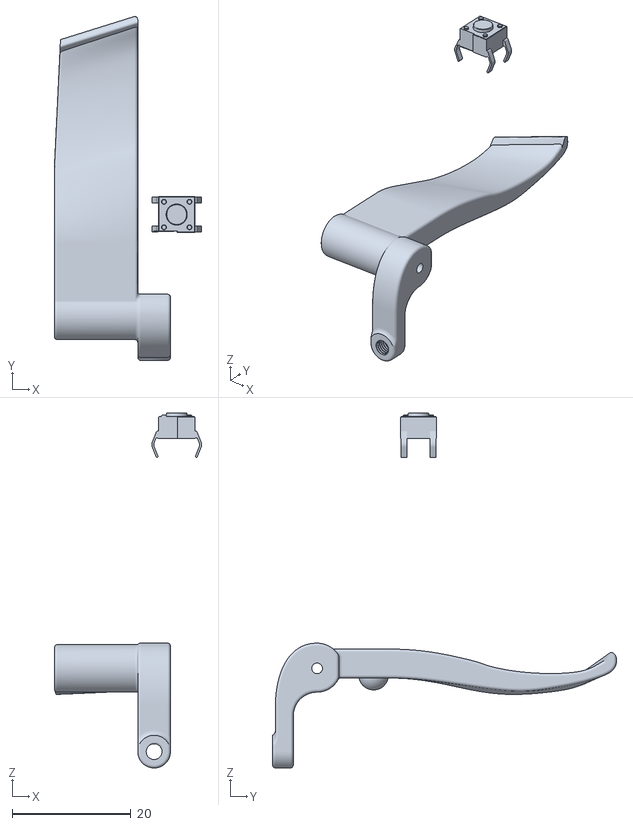
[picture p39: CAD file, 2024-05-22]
ReadyToPrint_Joystick/Paddle.stl
24.7 x 57.9 x 59.7

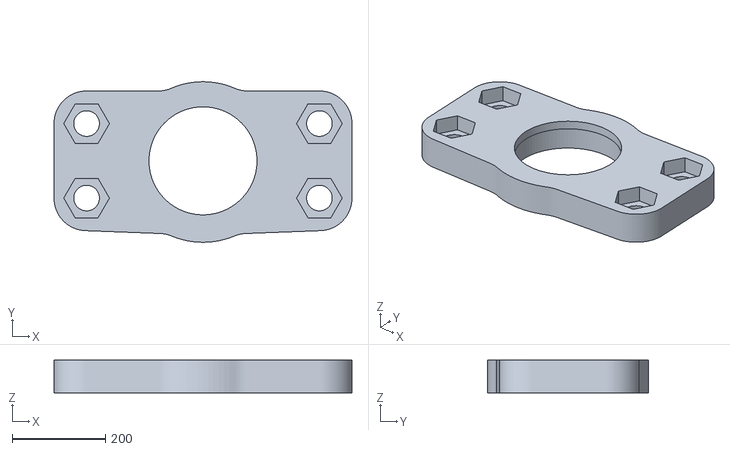
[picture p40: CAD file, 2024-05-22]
ReadyToPrint_Gimbal/gimbalcore_pot_v5.stl
640.0 x 345.0 x 70.0

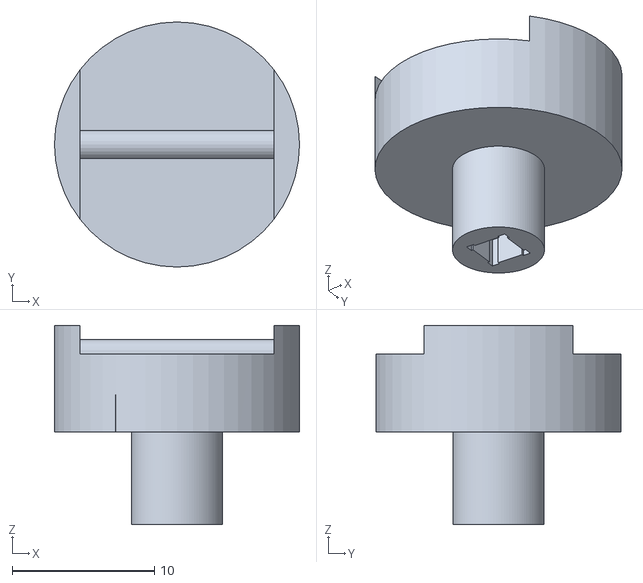
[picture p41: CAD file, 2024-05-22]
ReadyToPrint_Joystick/CMS_Hat.stl
17.2 x 17.2 x 14.0

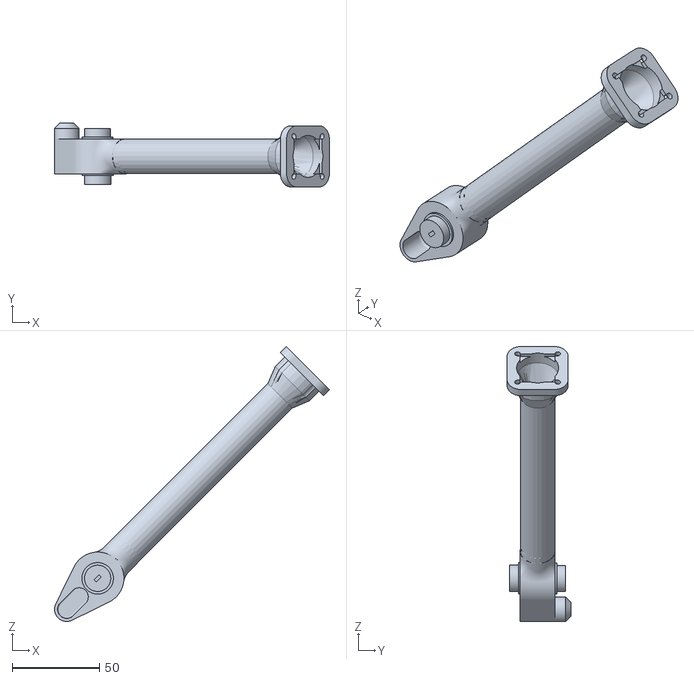
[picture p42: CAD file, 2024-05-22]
ReadyToPrint_Gimbal/Shaft_Long_twiston_compatible.stl
157.2 x 36.4 x 157.2

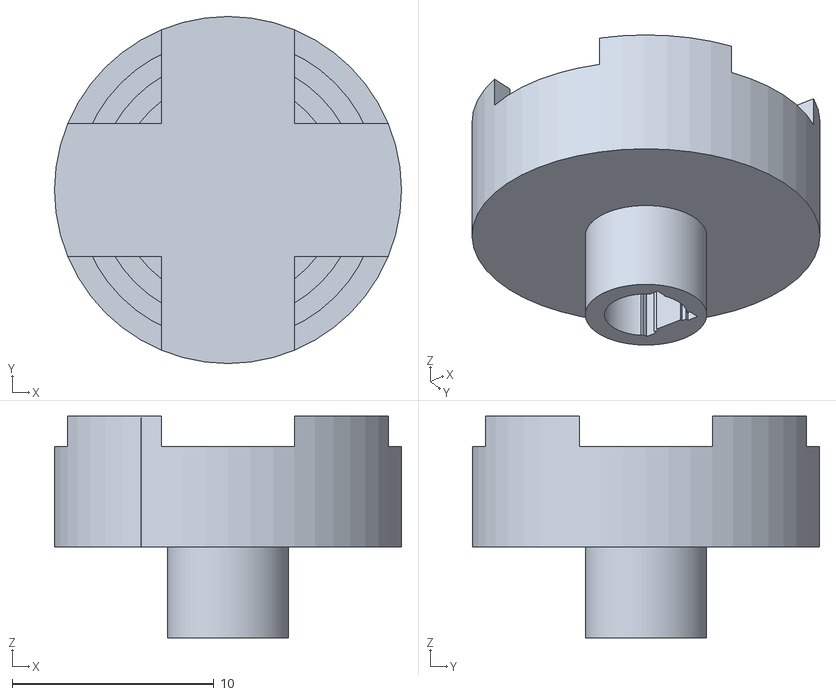
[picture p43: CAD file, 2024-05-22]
ReadyToPrint_Joystick/DMS_Hat.stl
17.2 x 17.2 x 11.0

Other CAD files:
ReadyToPrint_Gimbal/twiston_Spacer.stl
ReadyToPrint_Joystick/PinkieHolder.stl
ReadyToPrint_Gimbal/gimbal_frame_v3.stl
ReadyToPrint_Joystick/Top.stl
ReadyToPrint_Gimbal/connector v4.stl
ReadyToPrint_Joystick/NWS.stl
ReadyToPrint_Joystick/Pickle.stl
ReadyToPrint_Joystick/TMS_Hat.stl

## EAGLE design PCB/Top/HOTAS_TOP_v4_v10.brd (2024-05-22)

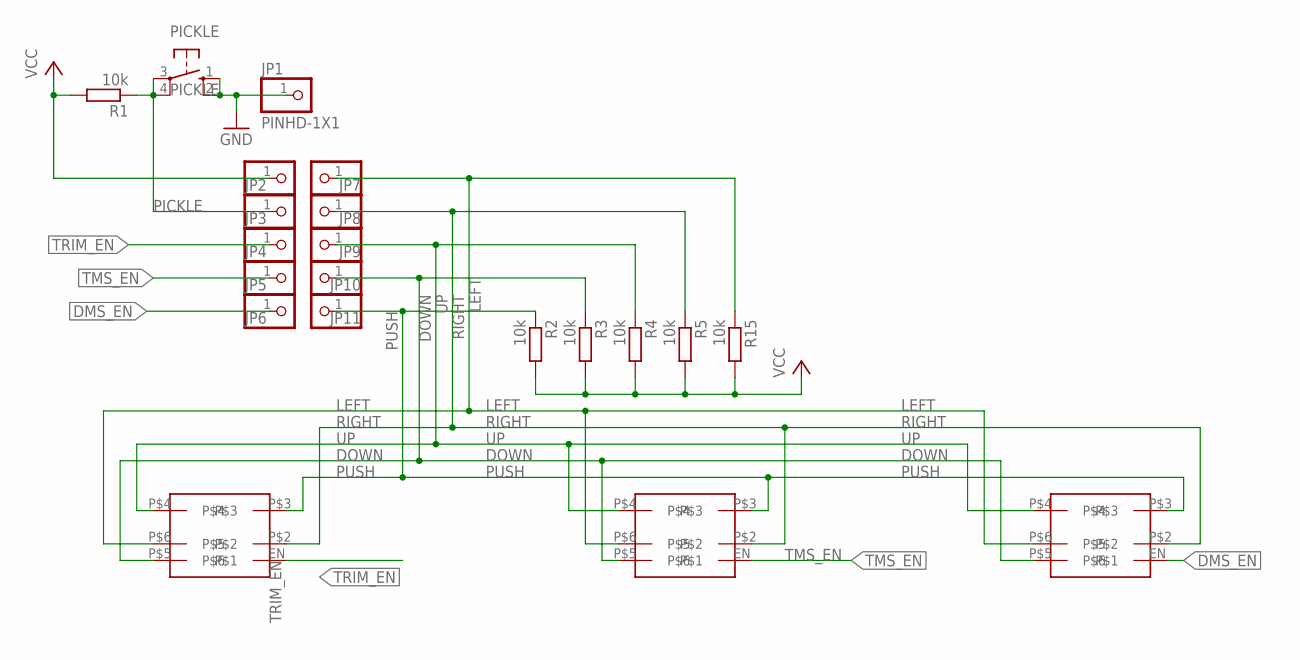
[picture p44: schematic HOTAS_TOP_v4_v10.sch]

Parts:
JP1, JP2, JP3, JP4, JP5, JP6, JP7, JP8, JP9, JP10, JP11: PINHD-1X1; 1X01
PICKLE: 10-XX; B3F-10XX
R1, R2, R3, R4, R5, R15: 10k; RESC3216X70
U$1, U$2, U$3: FIVEWAYHATSSMD

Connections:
DMS_EN: JP6.1, U$3.EN
DOWN: JP10.1, R3.1, U$1.P$5, U$2.P$5, U$3.P$5
GND: JP1.1, PICKLE.1 (S), PICKLE.2 (S1)
LEFT: JP7.1, R15.1, U$1.P$6, U$2.P$6, U$3.P$6
PICKLE: JP3.1, PICKLE.3, PICKLE.4 (P1), R1.1
PUSH: JP11.1, R2.1, U$1.P$3, U$2.P$3, U$3.P$3
RIGHT: JP8.1, R5.1, U$1.P$2, U$2.P$2, U$3.P$2
TMS_EN: JP5.1, U$2.EN
TRIM_EN: JP4.1, U$1.EN
UP: JP9.1, R4.1, U$1.P$4, U$2.P$4, U$3.P$4
VCC: JP2.1, R1.2, R2.2, R3.2, R4.2, R5.2, R15.2

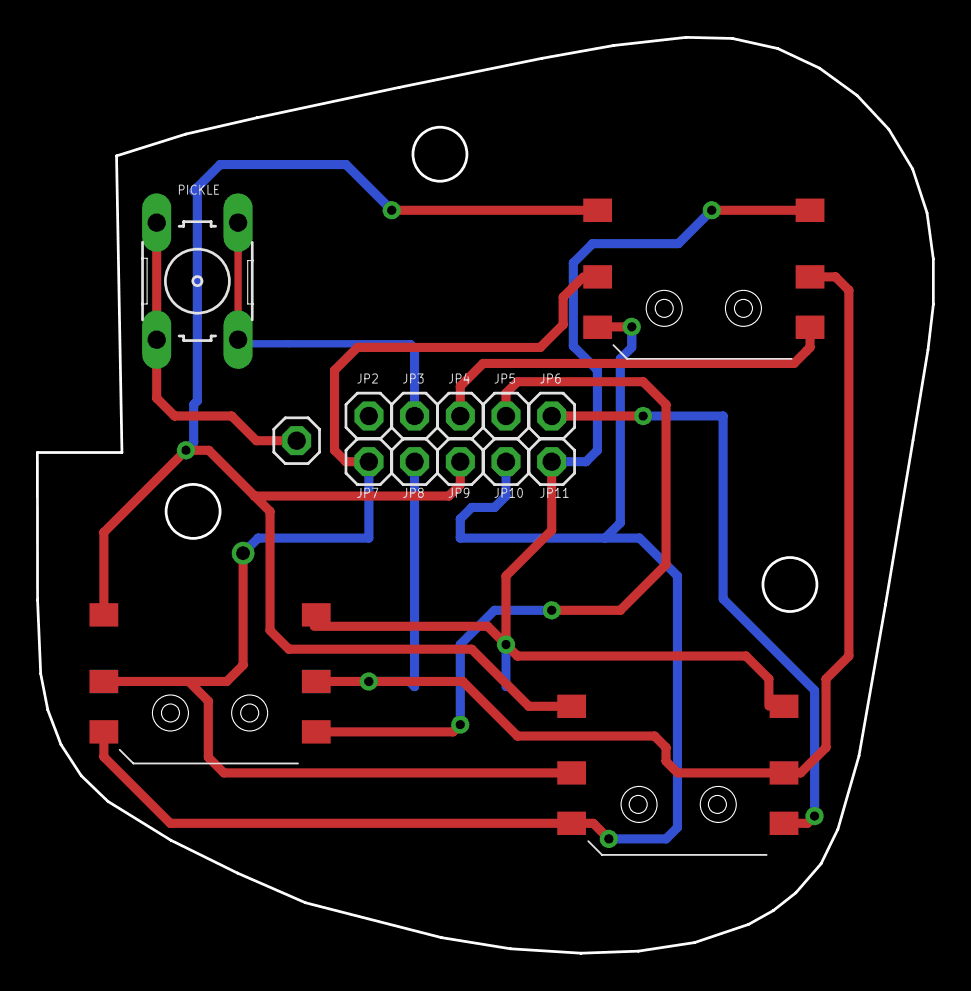
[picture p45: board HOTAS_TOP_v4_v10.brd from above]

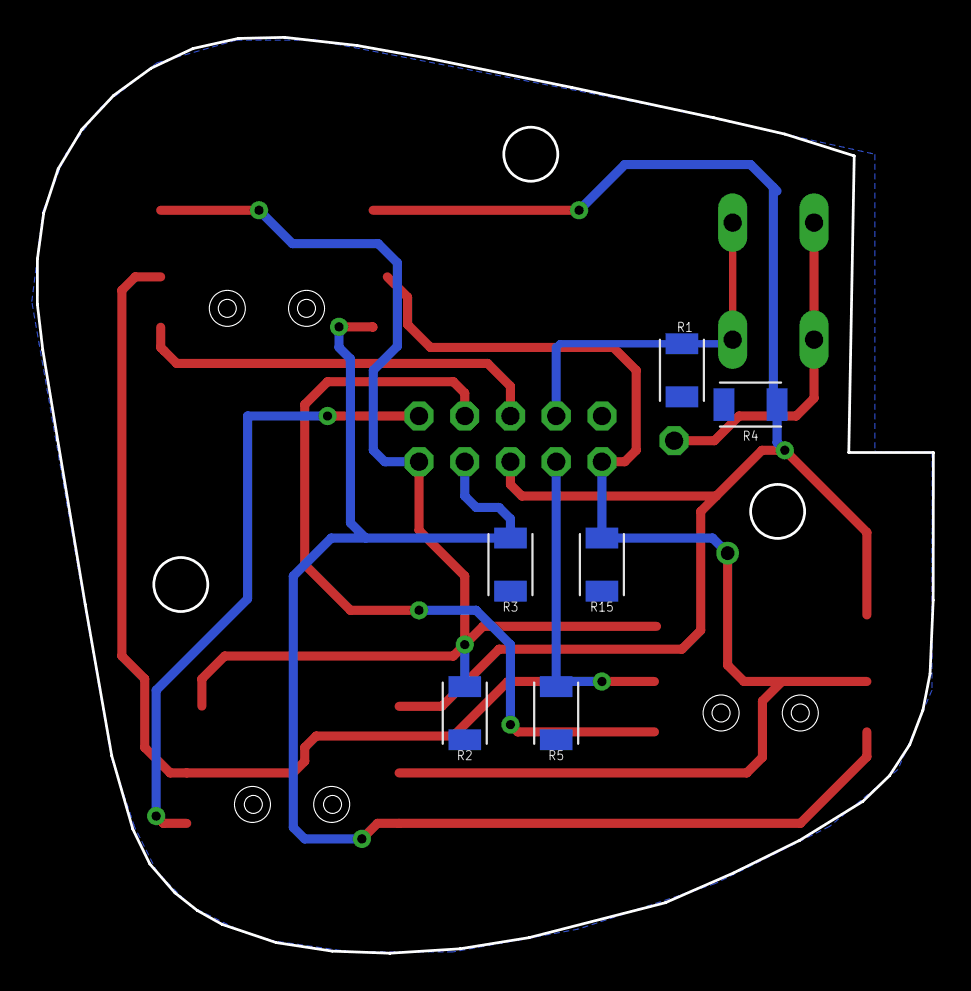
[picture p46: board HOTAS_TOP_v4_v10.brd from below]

Board: 2 copper layers, 49.8 x 50.9 mm, 21 parts (6 on the bottom side), 11 nets.

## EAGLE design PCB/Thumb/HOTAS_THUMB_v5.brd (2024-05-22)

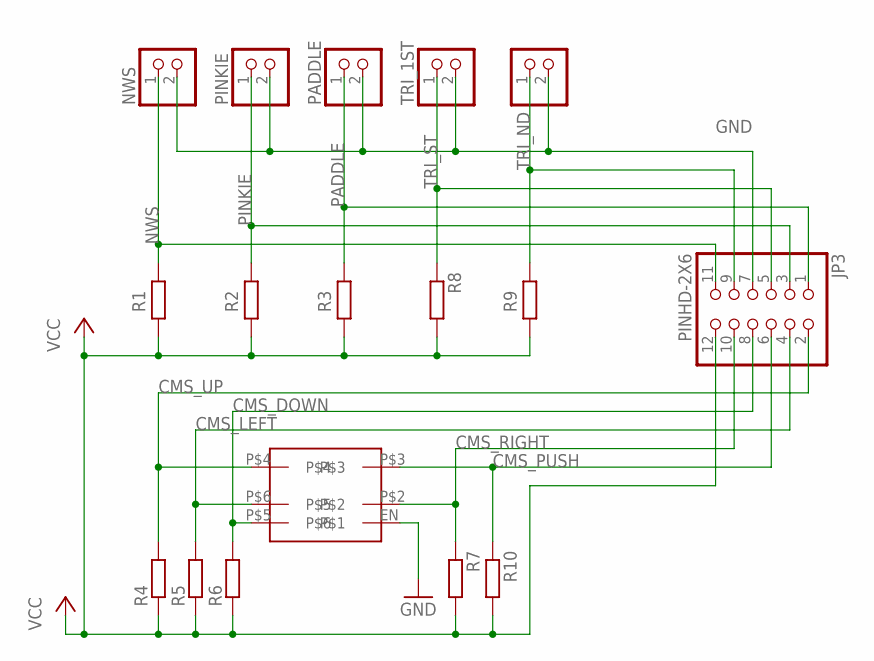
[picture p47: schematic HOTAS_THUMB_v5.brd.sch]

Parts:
JP3: PINHD-2X6; 2X06
NWS: PINHD-1X2; 1X02
PADDLE: PINHD-1X2; 1X02
PINKIE: PINHD-1X2; 1X02
R1, R2, R3, R4, R5, R6, R7, R8, R9, R10: R_CHIP-1206(3216-METRIC); RESC3216X70
TRI_1ST: PINHD-1X2; 1X02
TRI_ND: PINHD-1X2; 1X02
U$1: FIVEWAYHATSSMD

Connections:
CMS_DOWN: JP3.8, R6.2, U$1.P$5
CMS_LEFT: JP3.4, R5.2, U$1.P$6
CMS_PUSH: JP3.6, R10.1, U$1.P$3
CMS_RIGHT: JP3.10, R7.1, U$1.P$2
CMS_UP: JP3.2, R4.2, U$1.P$4
GND: JP3.7, NWS.2, PADDLE.2, PINKIE.2, TRI_1ST.2, TRI_ND.2, U$1.EN
NWS: JP3.11, NWS.1, R1.1
PADDLE: JP3.1, PADDLE.1, R3.1
PINKIE: JP3.3, PINKIE.1, R2.1
TRI_ND: JP3.9, R9.1, TRI_ND.1
TRI_ST: JP3.5, R8.1, TRI_1ST.1
VCC: JP3.12, R1.2, R2.2, R3.2, R4.1, R5.1, R6.1, R7.2, R8.2, R9.2, R10.2

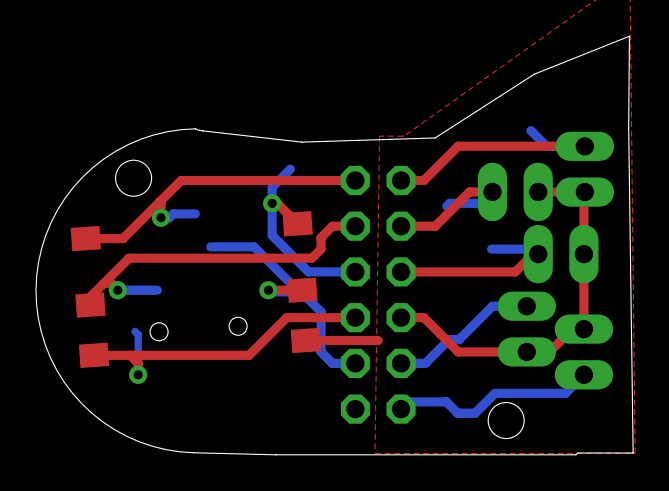
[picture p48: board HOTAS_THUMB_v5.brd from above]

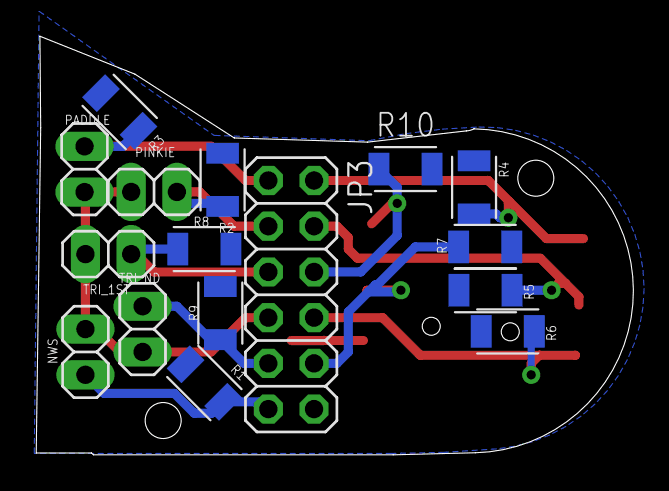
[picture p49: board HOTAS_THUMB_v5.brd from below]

Board: 2 copper layers, 33.2 x 23.3 mm, 17 parts (16 on the bottom side), 12 nets.

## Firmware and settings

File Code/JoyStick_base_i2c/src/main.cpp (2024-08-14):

#include <Arduino.h>
#include <Wire.h>
#include <Joystick.h>

#define buttonCount 26

//======I2C-All-Code======
// data to be received
struct I2cRxStruct
{
    bool Button[buttonCount]; // 26 bytes one byte for on button kinda wast of mem but who cares
};


bool LastButtonState[26]{0, 0, 0, 0, 0, 0, 0, 0, 0, 0, 0, 0, 0, 0, 0, 0, 0, 0, 0, 0, 0, 0, 0, 0, 0, 0};
bool currentButtonState = 0;

I2cRxStruct rxData;
const byte BaseAddress = 8;
const byte StickAddress = 9;
// prep for future ideas ?!
// const byte ThrottleAddress = 10;
// const byte PedalsAddress = 11;

//======I2C======
void requestData()
{
    byte stop = true;
    byte numBytes = buttonCount;
    Wire.requestFrom(StickAddress, numBytes, stop);
    // the request is immediately followed by the read for the response
    Wire.readBytes((byte *)&rxData, numBytes);
}

//======Joystick-All-Code======
Joystick_ Base_module( //  name the axies down below whatever you want, most games will recognize them anyways so dont even bother
    JOYSTICK_DEFAULT_REPORT_ID, JOYSTICK_TYPE_GAMEPAD,
    26, 0,               //  26  Buttons total on flightstick (might increas with an addition of a throttle); 0 hatswitches //i know i have hats on there butt i read them out as buttons
    true, true, false,   //  X,Y Axies used (roll and pitch yaw at some point with rudders maybe?)
    false, false, false, //  no "right" X,Y, and Z
    false, false, false, //  rudder, Throttle and accelorator
    false, false);       //  brakes and steering

void hotas()
{ //      Do da Hotas 
    Base_module.setYAxis(map(analogRead(A0),150,825,0,1023));
    Base_module.setXAxis(map(analogRead(A1),150,825,0,1023));

    Base_module.setButton(0, !rxData.Button[0]);
    Base_module.setButton(1, !rxData.Button[1]);
    Base_module.setButton(2, !rxData.Button[2]);
    Base_module.setButton(3, !rxData.Button[3]);
    Base_module.setButton(4, !rxData.Button[4]);
    Base_module.setButton(5, !rxData.Button[5]);
    Base_module.setButton(6, !rxData.Button[6]);
    Base_module.setButton(7, !rxData.Button[7]);
    Base_module.setButton(8, !rxData.Button[8]);
    Base_module.setButton(9, !rxData.Button[9]);
    Base_module.setButton(10, !rxData.Button[10]);
    Base_module.setButton(11, !rxData.Button[11]);
    Base_module.setButton(12, !rxData.Button[12]);
    Base_module.setButton(13, !rxData.Button[13]);
    Base_module.setButton(14, !rxData.Button[14]);
    Base_module.setButton(15, !rxData.Button[15]);
    Base_module.setButton(16, !rxData.Button[16]);
    Base_module.setButton(17, !rxData.Button[17]);
    Base_module.setButton(18, !rxData.Button[18]);
    Base_module.setButton(19, !rxData.Button[19]);
    Base_module.setButton(20, !rxData.Button[20]);
    Base_module.setButton(21, !rxData.Button[21]);
    Base_module.setButton(22, !rxData.Button[22]);
    Base_module.setButton(23, !rxData.Button[23]);
    Base_module.setButton(24, !rxData.Button[24]);
    Base_module.setButton(25, !rxData.Button[25]);
}

//======All-Arduino-Code======
void setup()
{
    //  I2C
    Wire.begin(BaseAddress);

    //  Pins in use
    pinMode(A0, INPUT);
    pinMode(A1, INPUT);

    //  Pins not in use (remeber to check if you use Arduino pro micro(does not hjave all pins) or Arduino Micro)
    
    pinMode(A2, OUTPUT);
    pinMode(A3, OUTPUT);
    pinMode(A4, OUTPUT);
    pinMode(A5, OUTPUT);
    pinMode(A6, OUTPUT);    // D4
    pinMode(A7, OUTPUT);    // D6
    pinMode(A8, OUTPUT);    // D8
    pinMode(A9, OUTPUT);    // D9
    pinMode(A10, OUTPUT);   // D10
    pinMode(A11,OUTPUT);    // D12
        //  and all  digital pins

    Base_module.begin();
    Base_module.setXAxisRange(0, 1023);
    Base_module.setYAxisRange(0, 1023);
}

void loop()
{
    hotas();
    requestData();
}
